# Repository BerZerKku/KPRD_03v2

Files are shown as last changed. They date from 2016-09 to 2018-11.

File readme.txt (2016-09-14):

Плата KPRD_03v2.
Сделана в OrCAD 16.6.

По замечанию Асакова номинал резисторов 1.2кОм изменен на 1.1кОм, иначе были не верные пороги срабатывания команд.

Предназначена для использования в АВАНТ К400.

Отличия от версии 03v1:
1. Цепь проверки сделана относительно виртуальнрой земли +12В, с целью 
исключить протекание постоянного тока через обмотки трансформаторов.

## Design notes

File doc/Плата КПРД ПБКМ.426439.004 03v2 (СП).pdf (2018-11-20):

№ | Наименование | Корпус | Кол. | Поз. | Примечание
| | | | | ПБКМ.426439.004

4

Изм | Лист | № докум. | Подп. | Дата
Разраб. | Щеблыкин М.В | | 14.09.16 | Плата КПРД 03v2 Спецификация | Лит. «Прософт-Системы» Н.контр. | Лист | Листов
Провер. | Вершинин А.С. | | 14.09.16 | | | 1 | 6

ООО
Назаренко А.Н. | 14.09.16
Утв. | Чирков А.Г.
1 | Сборочный чертеж
| ПБКМ.426439.004 rev.3 | 1

ДЕТАЛИ
3 | Плата печатная
| KPRD_03v2 | 1

ПРОЧИЕ ИЗДЕЛИЯ

Диоды

5 | 1N4148WS FAIRCHILD
| (1N4148WS-V VISHAY) | SOD-323 | 8 | VD8,VD17,VD22,VD27,VD32,VD37,
| | | | VD42,VD47
7 | BAT54C | SOT-23_3 | 8 | VD9,VD19,VD24,VD29,VD34,VD39,
| | | | VD44,VD49

Конденсаторы

10 | чип 0603 NP0 50В 1000пФ ±10%/±5% | 0805 | 16 | Навесной монтаж
11 | чип 0805 X7R 50В 0.1мкФ ±10% | 0805 | 10 | C1,C2,C4,C10,C13,C16,C19,C22,C25,C28
13 | чип 1206 X7R 100В 0.1мкФ ±10% | 1206 | 8 | C5,C11,C14,C17,C20,C23,C26,C29
15 | чип 1210 X7R 50В 10мкФ ±10%
| (чип 1210 X5R 50В 10мкФ ±10%,
| чип 1210 X7R 50В 4.7мкФ ±10%) | 1210 | 2 | C3,C12
19 | Микросхема UCC27537DBV TI | SOT-23_5 | 1 | DA1
23 | Оптрон ACPL-M50L-500E AVAGO | SMD_5 | 8 | AV1,AV3-AV9

# ПБКМ.426439.004

Лист

2 Изм | Лист | № докум. | Подп. | Дата

Разъемы

27 | 231-576/001-000 WAGO | 16 pins | 1 | X2
29 | DIN41612 09031966921 HARTING
| (DIN 41612 3*32 96 MR) | 96 pins | 1 | X1 | угл.вилка 96
31 | PLS-2 | PLS_2 | 1 | X4

Резисторы

35 | чип 1206 200 Ом ±5% | 1206 | 2 | R1,R3
37 | чип 1206 2 кОм ±5% | 1206 | 8 | R7,R20,R26,R32,R38,R44,R50,R56
39 | чип 2010 100 Ом ±5% | 2010 | 8 | R9,R21,R27,R33,R39,R45,R51,R57
43 | чип 2010 1.1 кОм ±5% | 2010 | 8 | R8,R19,R25,R31,R37,R43,R49,R55
45 | SQM 5.1 кОм 5Вт ±5% | 2 pins | 8 | R5,R17,R23,R29,R35,R41,R47,R53

Супрессоры

49 | SM6T6V8CA 6.8В двунаправленный | DO-214AA | 8 | VD5,VD15,VD20,VD25,VD30,VD35,
| | | | VD40,VD45
51 | SM6T18A 18В однонаправленный | DO-214AA | 8 | VD6,VD18,VD23,VD28,VD33,VD38,
| | | | VD43,VD48
53 | SM6T30CA 30В двунаправленный | DO-214AA | 1 | VD1
57 | Трансформатор 78253/55MVC
| MURATA | SM-6 | 8 | TV1,TV3-TV9

| | | | 3 Изм
Лист | № докум. | Подп. | Дата

Переменные данные для
исполнений:

ВАРИАНТ «8 КОМАНД 110»
43 | Резистор-чип 2010 1.1 кОм ±5% | 2010 | 8 | R6,R18,R24,R30,R36,R42,R48,R54
44 | Резистор MF-2 510 Ом 2Вт ±5% | 2 pins | 8 | R10,R22,R28,R34,R40,R46,R52,R58 | 430-560 Ом

ВАРИАНТ «8 КОМАНД 220»
41 | Резистор-чип 2010 1 кОм ±5% | 2010 | 8 | R6,R18,R24,R30,R36,R42,R48,R54
45 | Резистор SQM 5.1 кОм 5Вт ±5% | 2 pins | 8 | R10,R22,R28,R34,R40,R46,R52,R58

ВАРИАНТ «16 КОМАНД 110»

Диоды

5 | 1N4148WS FAIRCHILD
| (1N4148WS-V VISHAY) | SOD-323 | 8 | VD13,VD52,VD57,VD62,VD67,VD72,
| | | | VD77,VD82
7 | BAT54C | SOT-23_3 | 8 | VD14,VD54,VD59,VD64,VD69,VD74,
| | | | VD79,VD84

Конденсаторы

11 | чип 0805 X7R 50В 0.1мкФ ±10% | 0805 | 10 | C6,C7,C9,C31,C34,C37,C40,C43,C46,C49
13 | чип 1206 X7R 100В 0.1мкФ ±10% | 1206 | 8 | C8,C32,C35,C38,C41,C44,C47,C50
23 | Оптрон ACPL-M50L-500E AVAGO | SMD_5 | 8 | AV2,AV10-AV16
27 | Разъем 231-576/001-000 WAGO | 16 pins | 1 | X3

| | | | 4 Изм
Лист | № докум. | Подп. | Дата

Резисторы

35 | чип 1206 200 Ом ±5% | 1206 | 1 | R2
37 | чип 1206 2к Ом ±5% | 1206 | 8 | R13,R62,R68,R74,R80,R86,R92,R98
39 | чип 2010 100 Ом ±5% | 2010 | 8 | R15,R63,R69,R75,R81,R87,R93,R99
43 | чип 2010 1.1 кОм ±5% | 2010 | 24 | R6,R12,R14,R18,R24,R30,R36,R42,R48,
| | | | R54,R60,R61,R66,R67,R72,R73,R78,
| | | | R79,R84,R85,R90,R91,R96,R97
44 | MF-2 510 Ом 2Вт ±5% | 2 pins | 16 | R10,R16,R22,R28,R34,R40,R46,R52, | 430-560 Ом
| | | | R58,R64,R70,R76,R82,R88,R94,R100
45 | SQM 5.1 кОм 5Вт ±5% | 2 pins | 8 | R11,R59,R65,R71,R77,R83,R89,R95

Супрессоры

49 | SM6T6V8CA 6.8В двунаправленный | DO-214AA | 8 | VD10,VD50,VD55,VD60,VD65,VD70,
| | | | VD75,VD80
51 | SM6T18A 18В однонаправленный | DO-214AA | 8 | VD11,VD53,VD58,VD63,VD68,VD73,
| | | | VD78,VD83
57 | Трансформатор 78253/55MVC
| MURATA | SM-6 | 8 | TV2,TV10-TV16

ВАРИАНТ «16 КОМАНД 220»

Диоды

5 | 1N4148WS FAIRCHILD
| (1N4148WS-V VISHAY) | SOD-323 | 8 | VD13,VD52,VD57,VD62,VD67,VD72,
| | | | VD77,VD82
7 | BAT54C | SOT-23_3 | 8 | VD14,VD54,VD59,VD64,VD69,VD74,
| | | | VD79,VD84

| | | | 5 Изм
Лист | № докум. | Подп. | Дата

Конденсаторы

11 | чип 0805 X7R 50В 0.1мкФ ±10% | 0805 | 10 | C6,C7,C9,C31,C34,C37,C40,C43,C46,C49
13 | чип 1206 X7R 100В 0.1мкФ ±10% | 1206 | 8 | C8,C32,C35,C38,C41,C44,C47,C50
23 | Оптрон ACPL-M50L-500E AVAGO | SMD_5 | 8 | AV2,AV10-AV16
27 | Разъем 231-576/001-000 WAGO | 16 pins | 1 | X3

Резисторы

35 | чип 1206 200 Ом ±5% | 1206 | 1 | R2
37 | чип 1206 2 кОм ±5% | 1206 | 8 | R13,R62,R68,R74,R80,R86,R92,R98
39 | чип 2010 100 Ом ±5% | 2010 | 8 | R15,R63,R69,R75,R81,R87,R93,R99
41 | чип 2010 1 кОм ±5% | 2010 | 16 | R6,R12,R18,R24,R30,R36,R42,R48,R54,
| | | | R60,R66,R72,R78,R84,R90,R96
43 | чип 2010 1.1 кОм ±5% | 2010 | 8 | R14,R61,R67,R73,R79,R85,R91,R97
45 | SQM 5.1 кОм 5Вт ±5% | 2 pins | 24 | R10,R11,R16,R22,R28,R34,R40,R46,
| | | | R52,R58,R59,R64,R65,R70,R71,R76,
| | | | R77,R82,R83,R88,R89,R94,R95,R100

Супрессоры

49 | SM6T6V8CA 6.8В двунаправленный | DO-214AA | 8 | VD10,VD50,VD55,VD60,VD65,VD70,
| | | | VD75,VD80
51 | SM6T18A 18В однонаправленный | DO-214AA | 8 | VD11,VD53,VD58,VD63,VD68,VD73,
| | | | VD78,VD83
57 | Трансформатор 78253/55MVC
| MURATA | SM-6 | 8 | TV2,TV10-TV16

| | | | 6 Изм
Лист | № докум. | Подп. | Дата

Лист регистрции ревизий СП
№ ревизии | № замененных (измененных) страниц | Дата ревизии | Краткое содержание и причина внесения изменений | Примечание
0 | вновь | 18.02.14 | На замену «АВАНТ КПРД v3.2 СБ».
1 | 1-5 | 12.04.16 | Добавлены варианты исполнения. Добавлена поз.44.
2 | 2-5 | 14.09.16 | Номинал резисторов поз.43 изменен на 1.1кОм.
3 | 1 | 03.10.18 | Для поз.15 добавлены аналоги.
4 | 1 | 14.11.18 | Добавлены конденсаторы поз. 10

Вариант «8 команд 110» – 8 команд, 110В Вариант «8 команд 220» – 8 команд, 220В Вариант «16 команд 110» – 16 команд, 110В Вариант «16 команд 220» – 16 команд, 220В

Лист регистрции изменений СБ
№ ревизии | № замененных (измененных) страниц | Дата ревизии | Краткое содержание и причина внесения изменений | Примечание
0 | вновь | 18.02.14 | На замену «АВАНТ КПРД v3.2 СБ».
1 | 1,3 | 12.04.16 | Добавлен лист 3 с дополнительным видом различий вариантов исполнений.
2 | 3 | 14.09.16 | Номинал резисторов в Таблице 1 изменены с 1.2 кОм на 1.1 кОм.
3 | 1 | 14.11.18 | Добавлен пункт 8 ТТ (паять конденсаторы поз.10). Добавлен пункт 9 ТТ (поднять вывод 1 поз.19)

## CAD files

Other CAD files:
doc/Плата КПРД ПБКМ.426439.004 03v2 (СБ).dwg

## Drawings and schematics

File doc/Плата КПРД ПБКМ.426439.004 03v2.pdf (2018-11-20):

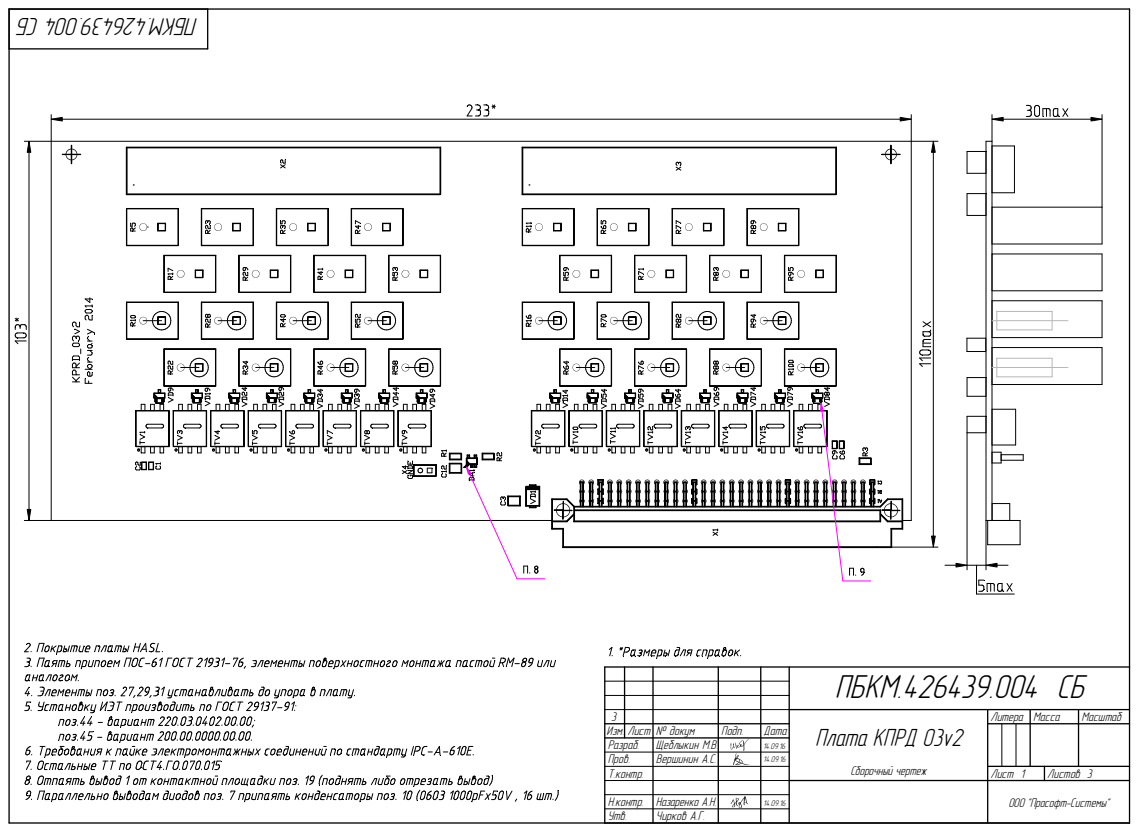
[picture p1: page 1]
Ëèñòîâ 3; Ìàññà; Ìàñøòàá; Ïîäï.; Äàòà; Óòâ.; Í.êîíòð.; Ò.êîíòð.; Ïðîâ.; Ðàçðàá.; Èçì. Ëèñò; ×èðêîâ À.Ã.; Íàçàðåíêî À.Í.; Âåðøèíèí À.Ñ.; Ùåáëûêèí Ì.Â.; № äîêóì; Ëèñò 1; Ëèòåðà; ÏÁÊÌ.426439.004 ÑÁ; Ïëàòà ÊÏÐÄ 03v2

Ñáîðî÷íûé ÷åðòåæ

ÎÎÎ "Ïðîñîôò-Ñèñòåìû"

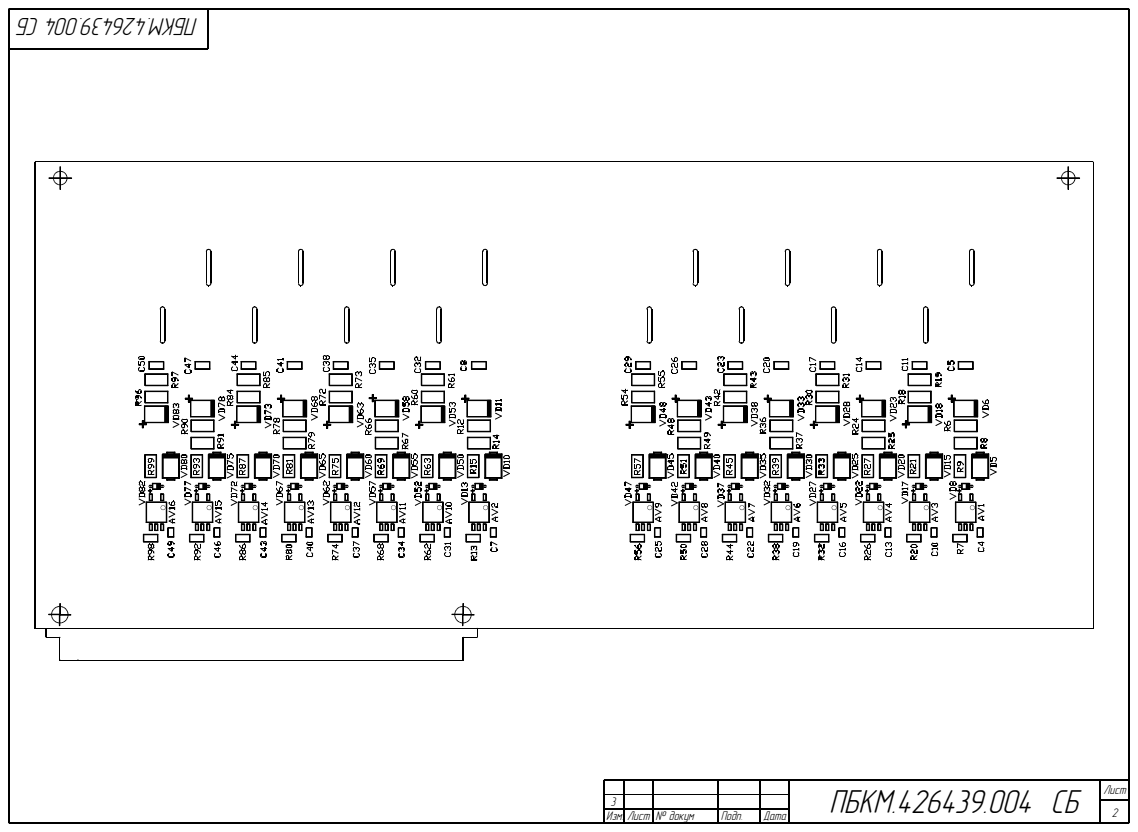
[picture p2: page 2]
Ëèñò; Èçì. Ëèñò № äîêóì; Ïîäï.; Äàòà; ÏÁÊÌ.426439.004 ÑÁ

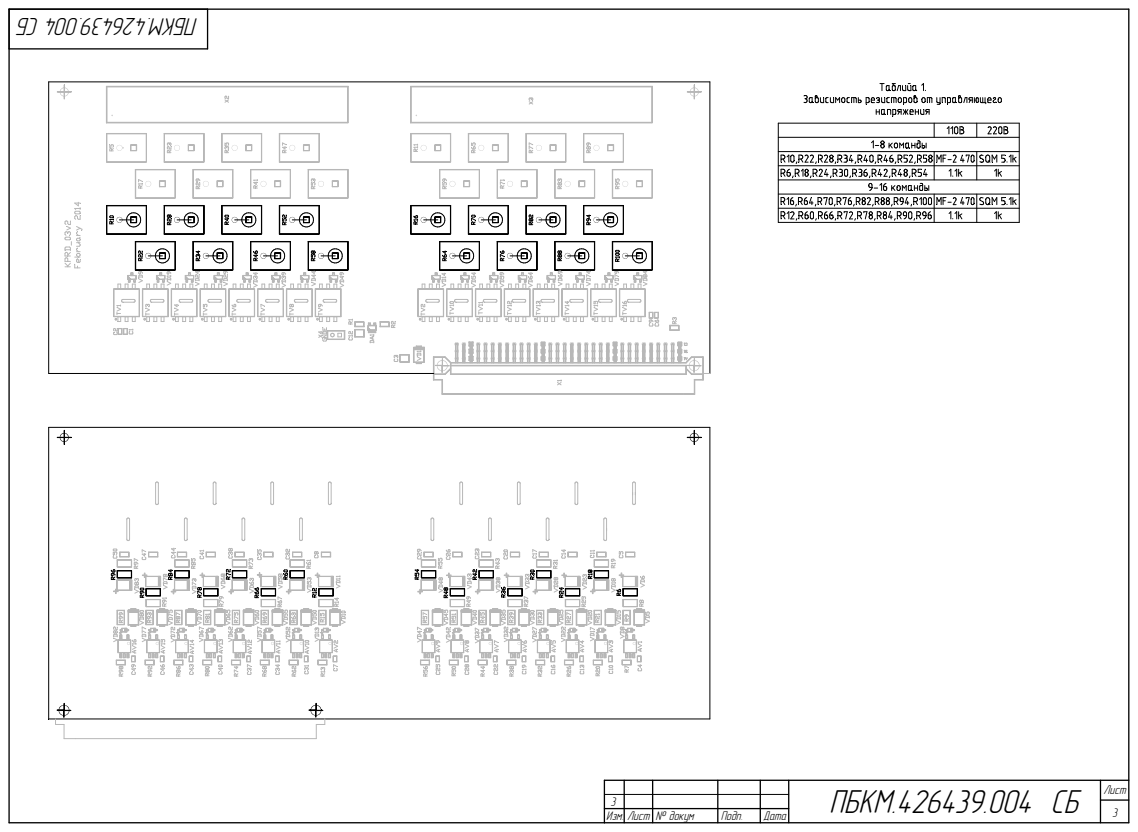
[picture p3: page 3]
Ëèñò; Èçì. Ëèñò № äîêóì; Ïîäï.; Äàòà; ÏÁÊÌ.426439.004 ÑÁ

№ | Наименование | Корпус | Кол. | Поз. | Примечание
| | | | | ПБКМ.426439.004

4

Изм | Лист | № докум. | Подп. | Дата
Разраб. | Щеблыкин М.В | | 14.09.16 | Плата КПРД 03v2 Спецификация | Лит. «Прософт-Системы» Н.контр. | Лист | Листов
Провер. | Вершинин А.С. | | 14.09.16 | | | 1 | 6

# ООО

Назаренко А.Н. | 14.09.16
Утв. | Чирков А.Г.
1 | Сборочный чертеж
| ПБКМ.426439.004 rev.3 | 1

## ДЕТАЛИ

3 | Плата печатная
| KPRD_03v2 | 1

## ПРОЧИЕ ИЗДЕЛИЯ

## Диоды

5 | 1N4148WS FAIRCHILD
| (1N4148WS-V VISHAY) | SOD-323 | 8 | VD8,VD17,VD22,VD27,VD32,VD37,
| | | | VD42,VD47
7 | BAT54C | SOT-23_3 | 8 | VD9,VD19,VD24,VD29,VD34,VD39,
| | | | VD44,VD49

## Конденсаторы

10 | чип 0603 NP0 50В 1000пФ ±10%/±5% | 0805 | 16 | Навесной монтаж
11 | чип 0805 X7R 50В 0.1мкФ ±10% | 0805 | 10 | C1,C2,C4,C10,C13,C16,C19,C22,C25,C28
13 | чип 1206 X7R 100В 0.1мкФ ±10% | 1206 | 8 | C5,C11,C14,C17,C20,C23,C26,C29
15 | чип 1210 X7R 50В 10мкФ ±10%
| (чип 1210 X5R 50В 10мкФ ±10%,
| чип 1210 X7R 50В 4.7мкФ ±10%) | 1210 | 2 | C3,C12
19 | Микросхема UCC27537DBV TI | SOT-23_5 | 1 | DA1
23 | Оптрон ACPL-M50L-500E AVAGO | SMD_5 | 8 | AV1,AV3-AV9

1
| | | | | ПБКМ.426439.004 | Лист 2 Изм
4
| Лист | № докум. | Подп. | Дата

## Разъемы

27 | 231-576/001-000 WAGO | 16 pins | 1 | X2
29 | DIN41612 09031966921 HARTING
| (DIN 41612 3*32 96 MR) | 96 pins | 1 | X1 | угл.вилка 96
31 | PLS-2 | PLS_2 | 1 | X4

## Резисторы

35 | чип 1206 200 Ом ±5% | 1206 | 2 | R1,R3
37 | чип 1206 2 кОм ±5% | 1206 | 8 | R7,R20,R26,R32,R38,R44,R50,R56
39 | чип 2010 100 Ом ±5% | 2010 | 8 | R9,R21,R27,R33,R39,R45,R51,R57
43 | чип 2010 1.1 кОм ±5% | 2010 | 8 | R8,R19,R25,R31,R37,R43,R49,R55
45 | SQM 5.1 кОм 5Вт ±5% | 2 pins | 8 | R5,R17,R23,R29,R35,R41,R47,R53

## Супрессоры

49 | SM6T6V8CA 6.8В двунаправленный | DO-214AA | 8 | VD5,VD15,VD20,VD25,VD30,VD35,
| | | | VD40,VD45
51 | SM6T18A 18В однонаправленный | DO-214AA | 8 | VD6,VD18,VD23,VD28,VD33,VD38,
| | | | VD43,VD48
53 | SM6T30CA 30В двунаправленный | DO-214AA | 1 | VD1
57 | Трансформатор 78253/55MVC
| MURATA | SM-6 | 8 | TV1,TV3-TV9

1
ПБКМ.426439.004 | 3 Изм
4
| Лист | № докум. | Подп. | Дата

## Переменные данные для исполнений:

## ВАРИАНТ «8 КОМАНД 110»

43 | Резистор-чип 2010 1.1 кОм ±5% | 2010 | 8 | R6,R18,R24,R30,R36,R42,R48,R54
44 | Резистор MF-2 510 Ом 2Вт ±5% | 2 pins | 8 | R10,R22,R28,R34,R40,R46,R52,R58 | 430-560 Ом

## ВАРИАНТ «8 КОМАНД 220»

41 | Резистор-чип 2010 1 кОм ±5% | 2010 | 8 | R6,R18,R24,R30,R36,R42,R48,R54
45 | Резистор SQM 5.1 кОм 5Вт ±5% | 2 pins | 8 | R10,R22,R28,R34,R40,R46,R52,R58

## ВАРИАНТ «16 КОМАНД 110»

## Диоды

5 | 1N4148WS FAIRCHILD
| (1N4148WS-V VISHAY) | SOD-323 | 8 | VD13,VD52,VD57,VD62,VD67,VD72,
| | | | VD77,VD82
7 | BAT54C | SOT-23_3 | 8 | VD14,VD54,VD59,VD64,VD69,VD74,
| | | | VD79,VD84

## Конденсаторы

11 | чип 0805 X7R 50В 0.1мкФ ±10% | 0805 | 10 | C6,C7,C9,C31,C34,C37,C40,C43,C46,C49
13 | чип 1206 X7R 100В 0.1мкФ ±10% | 1206 | 8 | C8,C32,C35,C38,C41,C44,C47,C50
23 | Оптрон ACPL-M50L-500E AVAGO | SMD_5 | 8 | AV2,AV10-AV16
27 | Разъем 231-576/001-000 WAGO | 16 pins | 1 | X3

1
ПБКМ.426439.004 | 4 Изм
4
| Лист | № докум. | Подп. | Дата

## Резисторы

35 | чип 1206 200 Ом ±5% | 1206 | 1 | R2
37 | чип 1206 2к Ом ±5% | 1206 | 8 | R13,R62,R68,R74,R80,R86,R92,R98
39 | чип 2010 100 Ом ±5% | 2010 | 8 | R15,R63,R69,R75,R81,R87,R93,R99
43 | чип 2010 1.1 кОм ±5% | 2010 | 24 | R6,R12,R14,R18,R24,R30,R36,R42,R48,
| | | | R54,R60,R61,R66,R67,R72,R73,R78,
| | | | R79,R84,R85,R90,R91,R96,R97
44 | MF-2 510 Ом 2Вт ±5% | 2 pins | 16 | R10,R16,R22,R28,R34,R40,R46,R52, | 430-560 Ом
| | | | R58,R64,R70,R76,R82,R88,R94,R100
45 | SQM 5.1 кОм 5Вт ±5% | 2 pins | 8 | R11,R59,R65,R71,R77,R83,R89,R95

## Супрессоры

49 | SM6T6V8CA 6.8В двунаправленный | DO-214AA | 8 | VD10,VD50,VD55,VD60,VD65,VD70,
| | | | VD75,VD80
51 | SM6T18A 18В однонаправленный | DO-214AA | 8 | VD11,VD53,VD58,VD63,VD68,VD73,
| | | | VD78,VD83
57 | Трансформатор 78253/55MVC
| MURATA | SM-6 | 8 | TV2,TV10-TV16

## ВАРИАНТ «16 КОМАНД 220»
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

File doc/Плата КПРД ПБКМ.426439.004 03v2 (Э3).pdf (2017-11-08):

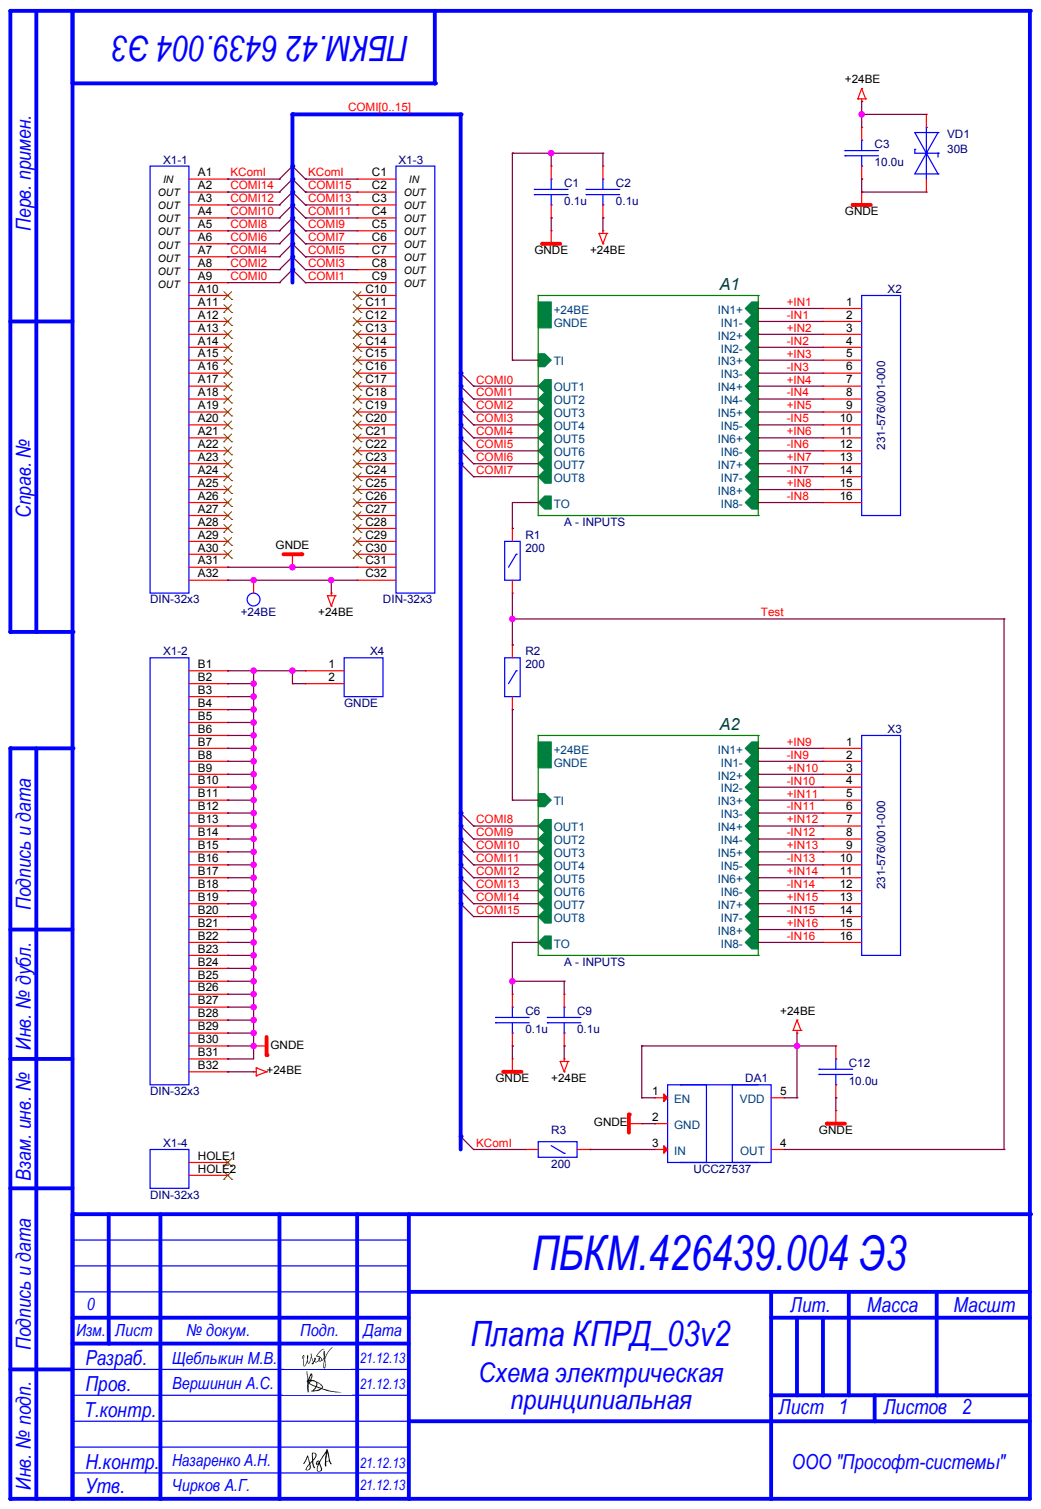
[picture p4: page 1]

Инв. № подп. Подпись и дата Взам. инв. № Инв. № дубл. Подпись и дата

ПБКМ.426439.004 Э3

0 | | | | | Плата КПРД_03v2 Схема электрическая принципиальная | Лит. | Масса | Масшт
Изм. | Лист | № докум. | Подп. | Дата
Разраб. | | Щеблыкин М.В. | | 21.12.13
Пров. | Вершинин А.С. | | 21.12.13
Т.контр. | | | | | Лист 1 | Листов 2

Н.контр. | Назаренко А.Н. | 21.12.13
Утв. | Чирков А.Г. | 21.12.13

ООО "Прософт-системы"

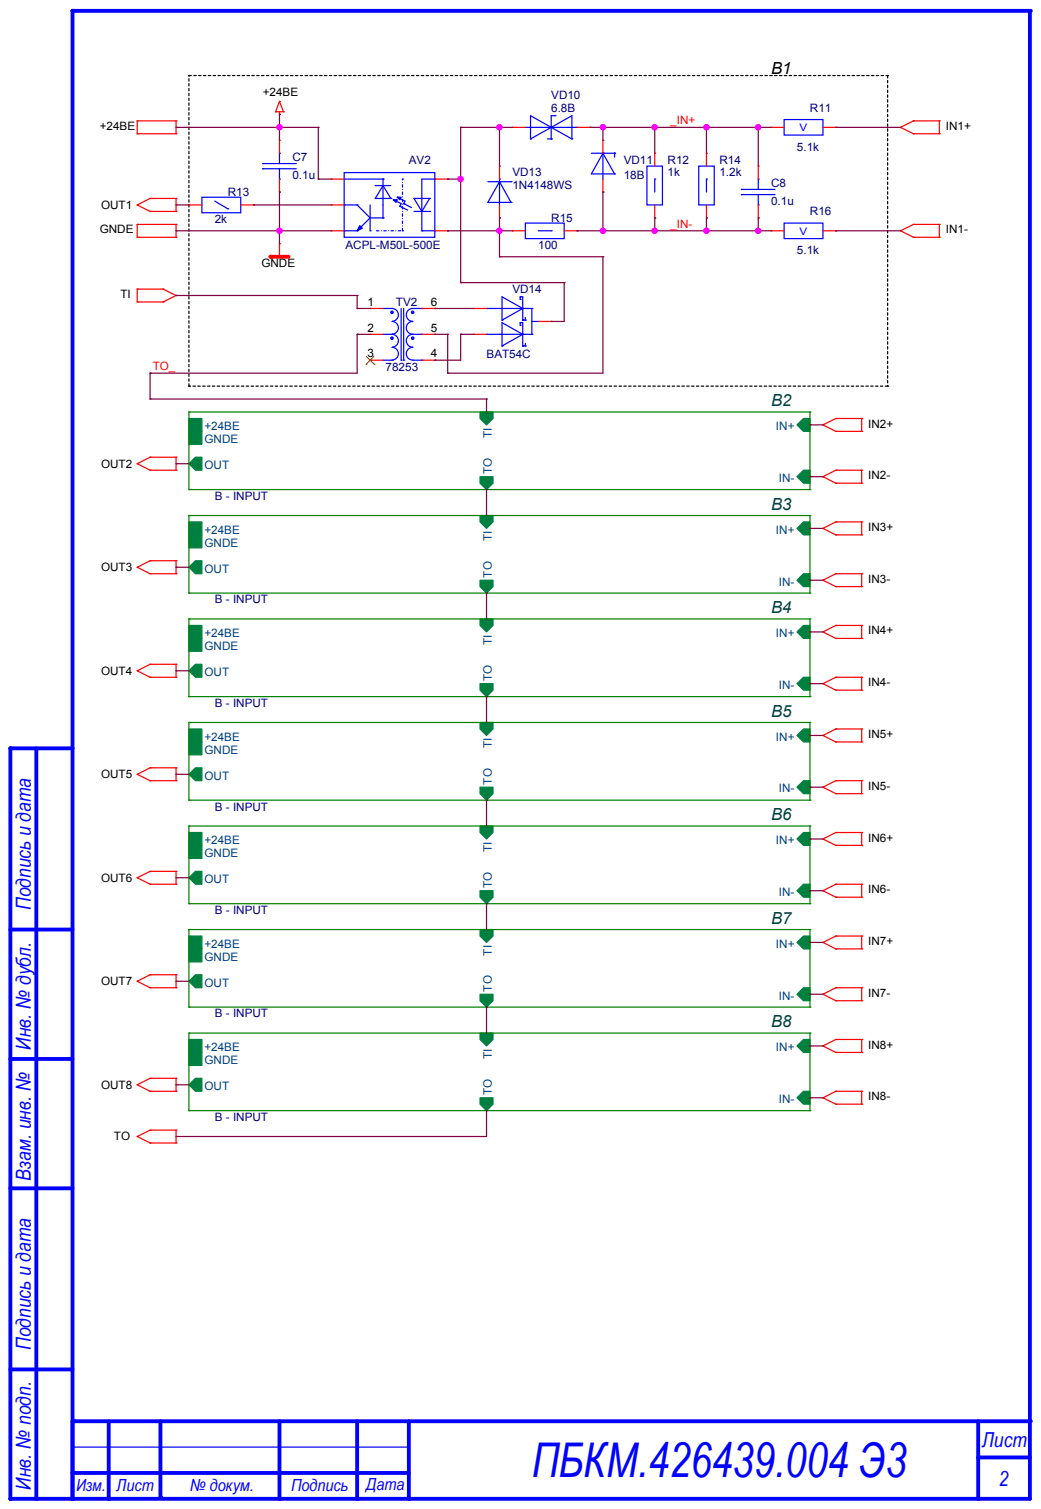
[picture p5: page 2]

Инв. № подп. Подпись и дата Взам. инв. № Инв. № дубл. П

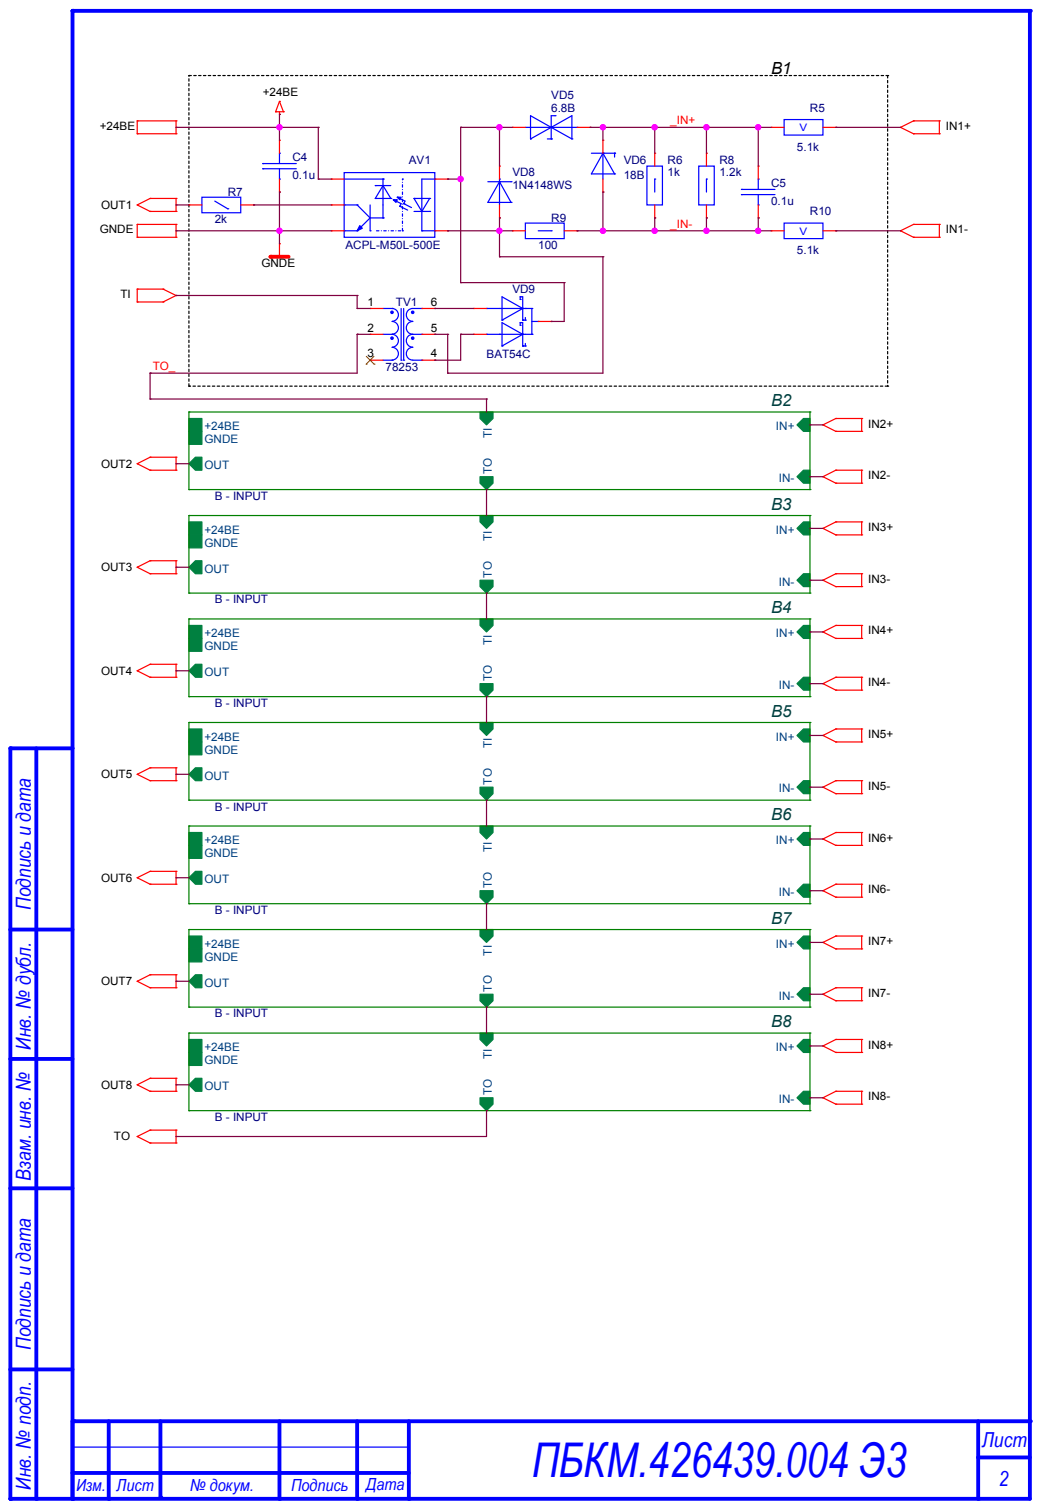
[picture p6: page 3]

Инв. № подп. Подпись и дата Взам. инв. № Инв. № дубл. П

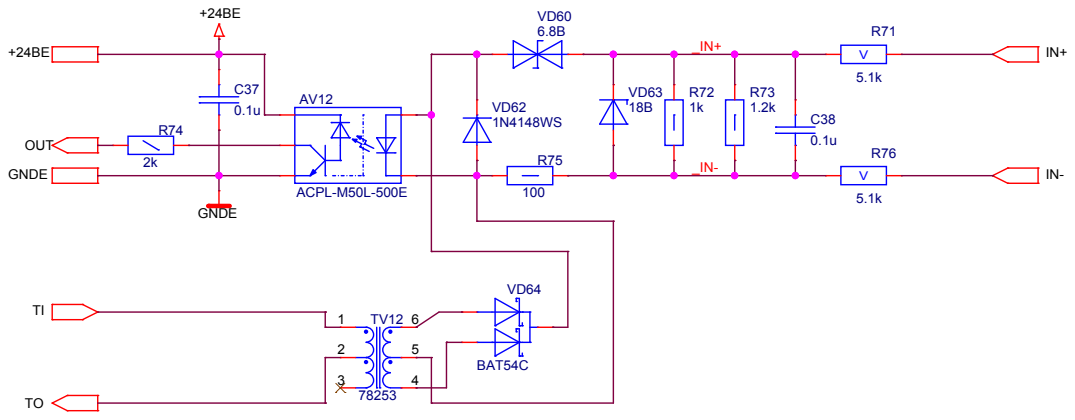
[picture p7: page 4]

Инв. № подп. Подпись и дата Взам. инв. № Инв. № дубл. Подпись и дата

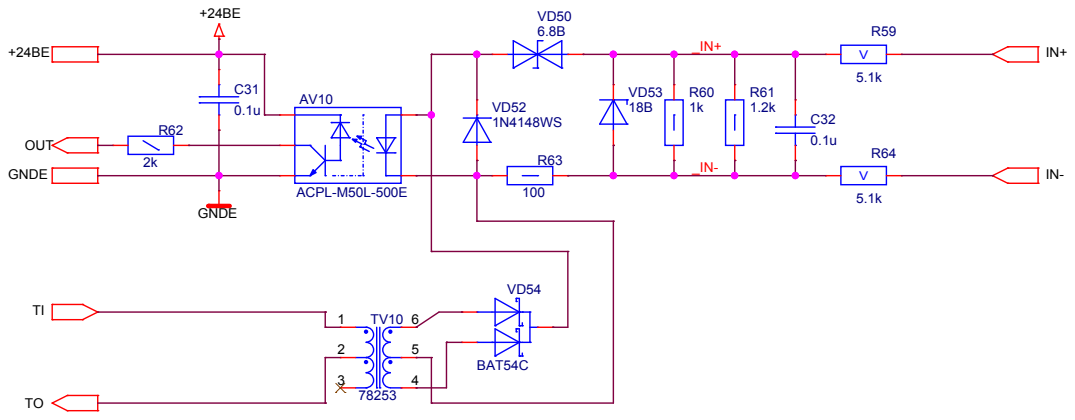
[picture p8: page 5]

Инв. № подп. Подпись и дата Взам. инв. № Инв. № дубл. Подпись и дата

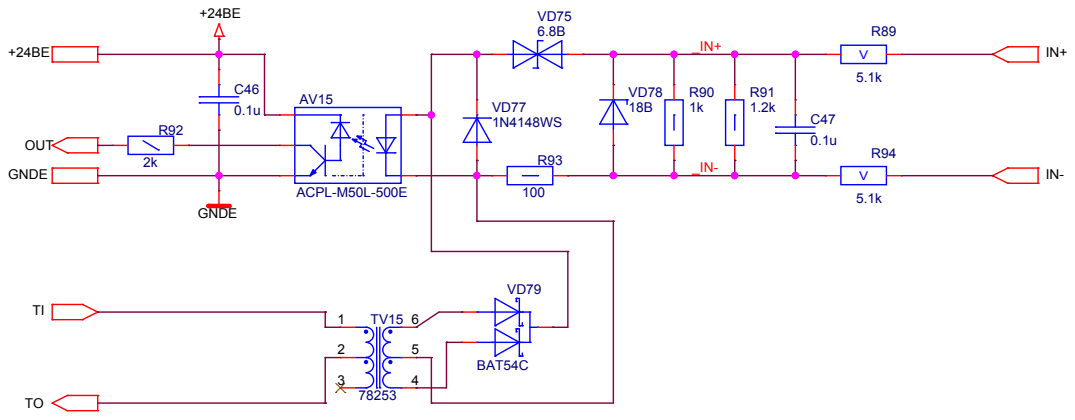
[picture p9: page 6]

Инв. № подп. Подпись и дата Взам. инв. № Инв. № дубл. Подпись и дата

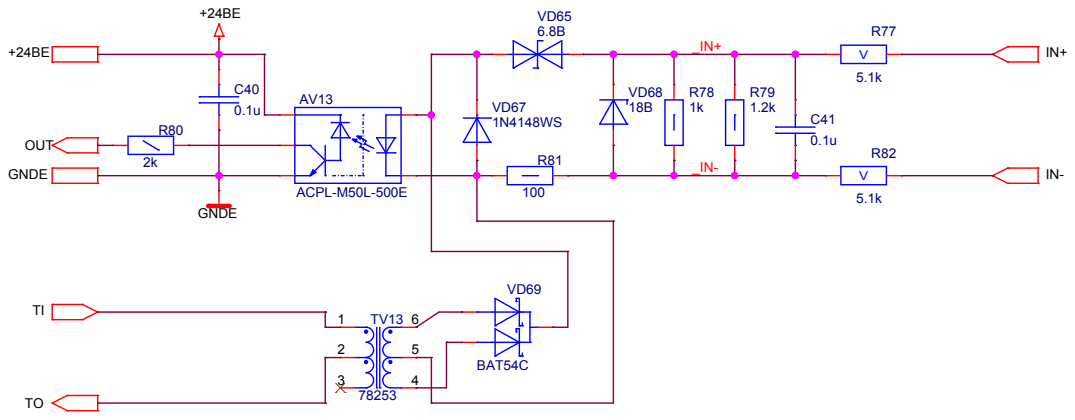
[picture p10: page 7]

Инв. № подп. Подпись и дата Взам. инв. № Инв. № дубл. Подпись и дата

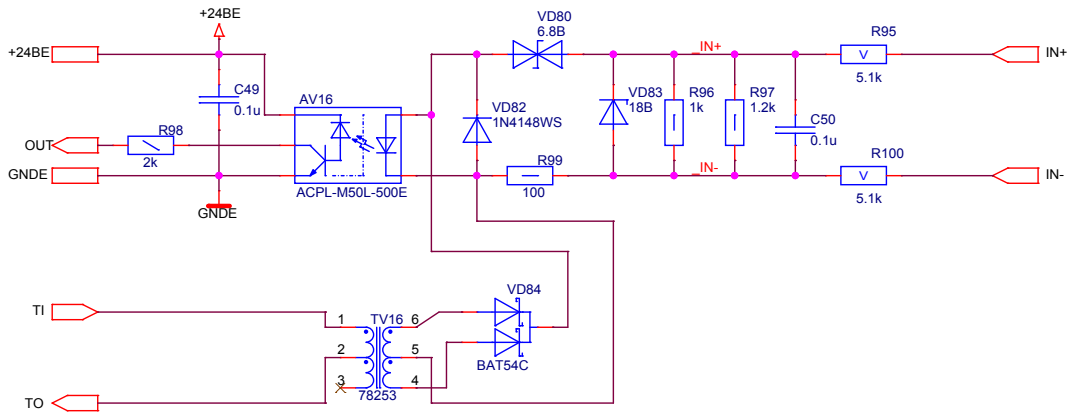
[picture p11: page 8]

Инв. № подп. Подпись и дата Взам. инв. № Инв. № дубл. Подпись и дата

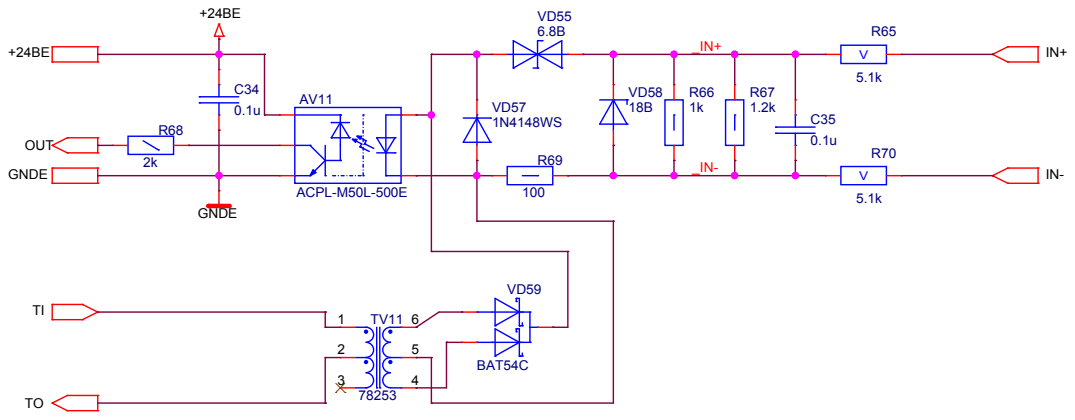
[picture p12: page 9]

Инв. № подп. Подпись и дата Взам. инв. № Инв. № дубл. Подпись и дата


Инв. № подп. Подпись и дата Взам. инв. № Инв. № дубл. Подпись и дата


Инв. № подп. Подпись и дата Взам. инв. № Инв. № дубл. Подпись и дата


Инв. № подп. Подпись и дата Взам. инв. № Инв. № дубл. Подпись и дата


Инв. № подп. Подпись и дата Взам. инв. № Инв. № дубл. Подпись и дата


Инв. № подп. Подпись и дата Взам. инв. № Инв. № дубл. Подпись и дата


Инв. № подп. Подпись и дата Взам. инв. № Инв. № дубл. Подпись и дата


Инв. № подп. Подпись и дата Взам. инв. № Инв. № дубл. Подпись и дата


Инв. № подп. Подпись и дата Взам. инв. № Инв. № дубл. Подпись и дата

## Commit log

2014-02-04 Вновь. Нарисована схема и сделана предварительная трассировка. Внесены следующие изменения: переделана цепь проверки, теперь через трансформаторы не должна идти постоянная состовляющая тока.
    [KPRD_03V2.DSN, KPRD_03v2.brd]
2014-02-04 Плата подготовлена к производству.
    [KPRD_03V2.DSN, KPRD_03v2.brd, nc_param.txt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]
2014-02-04 Добавлен файл настроек герберов.
    [art_param.txt]
2014-02-06 Добавлена документация.
    [KPRD_03V2.DSN, Плата КПРД KPRD_03v2 (СБ).dwg]
2015-02-18 Изменены децимальные номера.
    [KPRD_03V2.DSN, Плата КПРД KPRD_03v2 (СБ).dwg, Плата КПРД ПБКМ.426439.004 03v2 (СБ).dwg]
2016-04-13 Добавлены вариантные исполнения для 110В.
    [Плата КПРД ПБКМ.426439.004 03v2 (СБ).dwg]
2016-04-13 Исправлены варианты на 16 команд. не были добавлены резисторы для первых 8 команд.
2016-04-13 Исправлено кол-во резисторов SQM в варианте 220В 16 команд.
2016-09-14 По замечанию Асакова номинал резисторов 1.2кОм изменен на 1.1кОм, иначе были не верные пороги срабатывания команд.
2016-09-14 СБ рев.2 Номиналы резисторов изменены и на СБ.
    [Плата КПРД ПБКМ.426439.004 03v2 (СБ).dwg]
2016-11-29 Добавлены гербера для пасты.
    [KPRD_03v2.brd]
2017-11-08 Исправлен документ Э3.
2018-07-23 Добавлены файлы заказа.
    [KPRD_03v2 04.02.14.xls, art_param.txt, nc_param.txt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]
2018-11-14 добавлена изм. 3 заменены только документы-чертежи конденсаторы параллельно диодам BAT54 поднята ножка pin1=EN для UCC27537 todo: проверить и сгенерить pdf
    [KPRD_03V2.DSN, Плата КПРД ПБКМ.426439.004 03v2 (СБ).dwg]
2018-11-14 в СП добавлены конденсаторы
2018-11-14 обновлен pdf файл
    [Плата КПРД ПБКМ.426439.004 03v2 (СБ).dwg]
2018-11-14 в СП внесены правки до изм 3.
2018-11-20 В СП добавлена "пропавшая" ревизия 3.
